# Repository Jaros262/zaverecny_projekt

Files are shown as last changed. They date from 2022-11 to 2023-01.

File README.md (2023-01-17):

# Záverečný projekt
Projekt se bude věnovat hardwaru, konkrétně pak tanku na dálkové ovládání.
# Úvod
Rozhodl jsem vytvořit vozidlo na dálkové ovládání, protože mě práce s Arduino moduly vždy zajímala a vždy jsem chtěl vytvářet modely historických vozidel, primárně pak tanků. 

Hlavním cílem mého projektu bylo vytvoření funkčního tanku, který bude modelově odpovídat předloze historického tanku Tiger I. Tank je vytvořený za pomocí programu Inventor přeložený do formátu gcode a vytištěný na 3D tiskárně. Program tanku je v jazyce Arduino, který je kombinací jazyků C a C++.  

Uživatel se připojí k tanku pomocí ovladače a může si vybrat mezi dvěma módy ovládání, poté již bezstarostně ovládá pohyb tanku a otáčení věže.

> Pro prohlížení souborů doporučuju používat [AUTODESK Viewer](https://360.autodesk.com/viewer "AUTODESK Viewer")

## Rozdělení projektu na branche

1. Základní funkce
   - [x] Kód na pohyb motorů pomocí drátem zapojeným joystickem
   - [x] Schéma zapojení komponentů
   - [x] Video obsahující ukázku funkčnosti
   - [x] Reference
   
2. Prototyp 3D modelu "auta"
   - [x] Samotné části prototypu
   - [x] Screenshoty prototypu
   - [x] Využité technologie

## Cíle

1. Nákup komponentů a diskuze s učiteli
   - [x] Nákup komponentů
   - [X] Diskuze

2. Navrhnout a sestrojit prototip základny
   - [x] Prototyp V1

3. Zprovoznění zařízení BLUETOOTH
   - [x] Vlastnit komponent
   - [x] Zprovoznit komunikaci s mobilem
   - [x] Přehodnocení a konečné rozhodnutí zhotovit vlastní kontroler místo mobilu
   - [x] Návrh kontroleru
   - [ ] Komunikace mezi dvěmi arduino
   - [x] Konstrukce kontroleru
   - [ ] Celkové ovládání modelu skrz kontroler
   
4. Navrhnout kód na pohyb koly
   - [x] Základní Kód
   - [x] Funkce kol
   - [x] Využití joysticku na ovládání kol

5. Navrhnout konečný model tanku
   - [x] Pásy
   - [x] Ozubené kola
   - [x] Systém odpružení pro ostatní kola
   - [x] Dolní část modelu
   - [x] Horní část modelu
   - [x] Věž
   - [X] Dělo
   - [x] Prostory pro moduly v modelu
   - [ ] Detaily modelu
6. Navrhnout finální kód pro controller
   - [X] Funkčnost Joysticků
   - [X] Funkčnost tlačítka/tlačítek (dle potřeby)
   - [X] Funkce dvou rozdílných módů ovládání
   - [X] Funkce Bluetooth
   - [ ] úspěšný test
   - [ ] funkční
7. Navrhnout finální kód pro model
   - [ ] Funkčnost ovládání motorů skrze bluetooth
   - [ ] Funkčnost ovládání serva skrze bluetooth
   - [x] Fungující odpojování baterie
   - [x] Funkce vypnutí celého modelu
   - [ ] úspěšný test
   - [ ] funkční
   
## rozvržení času
- Osobně bych řekl, že jsem na projektu strávil něco mezi 130 - 200 hodin.

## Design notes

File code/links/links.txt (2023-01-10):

DC motors:
https://create.arduino.cc/projecthub/ryanchan/how-to-use-the-l298n-motor-driver-b124c5
switch:
https://arduinogetstarted.com/tutorials/arduino-switch
stm32-connection:
https://www.youtube.com/watch?v=K-jYSysmw9w
OLED Display:
https://www.youtube.com/watch?v=tXaeRzaBwBY
HC-05:
https://www.youtube.com/embed/I2qFXSe0W3w?feature=oembed&autoplay=1
https://create.arduino.cc/projecthub/embeddedlab786/how-to-configure-and-pair-two-hc-05-bluetooth-modules-fa8ce2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
https://howtomechatronics.com/tutorials/arduino/how-to-configure-pair-two-hc-05-bluetooth-module-master-slave-commands/
https://www.instructables.com/Arduino-Two-Way-Communication-Via-Bluetooth-HC-05/
Servo with joystick:
https://maker.pro/arduino/tutorial/how-to-control-servo-motors-with-an-arduino-and-joystick
Button ideas:
https://github.com/poelstra/arduino-multi-button
https://stackoverflow.com/questions/28653134/arduino-button-ispressed-is-not-working
ideas:
https://maker.pro/arduino/projects/how-to-control-an-arduino-robot-with-a-ps4-bluetooth-controller
https://projecthub.arduino.cc/samanfern/c71cd04b-79fd-4d0a-8a4b-b1dacc2f7725
https://www.instructables.com/DIY-Joystick-Controlled-Remote-Car-Using-Arduino/

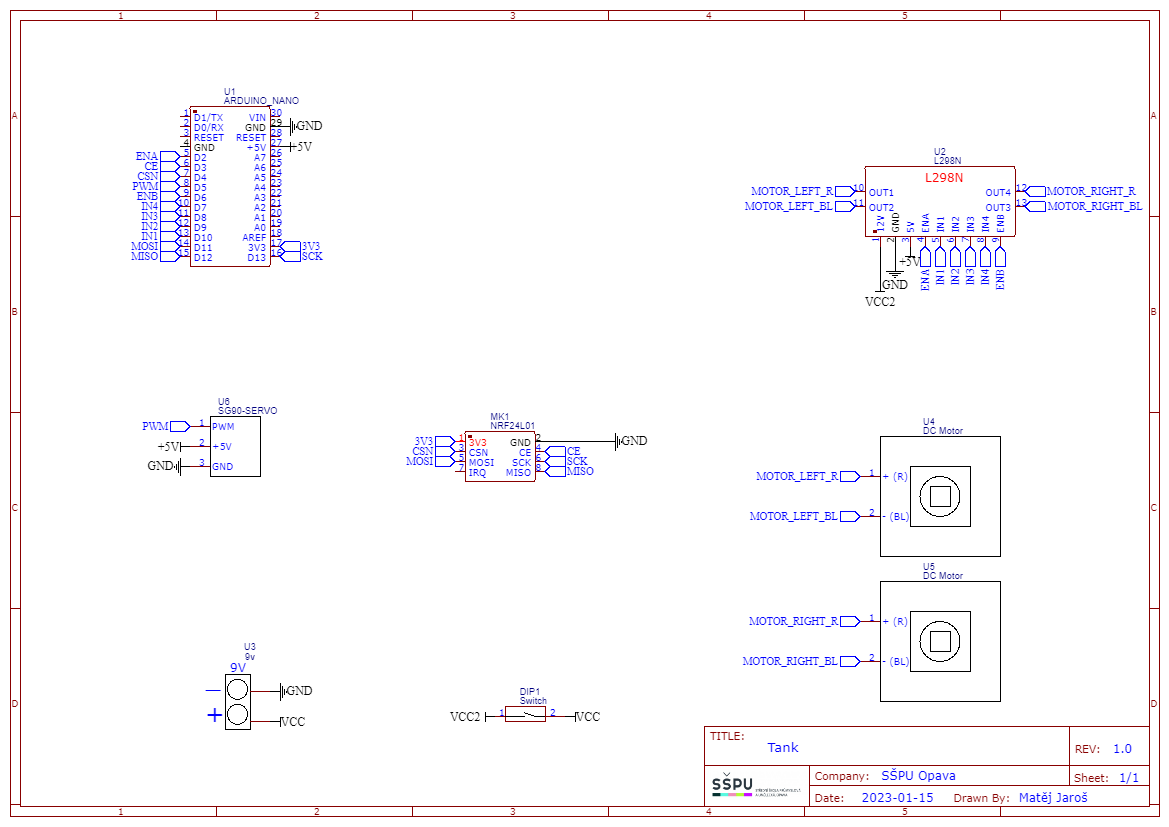
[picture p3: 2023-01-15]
img_files/Schematic_tank_2023-01-15.png

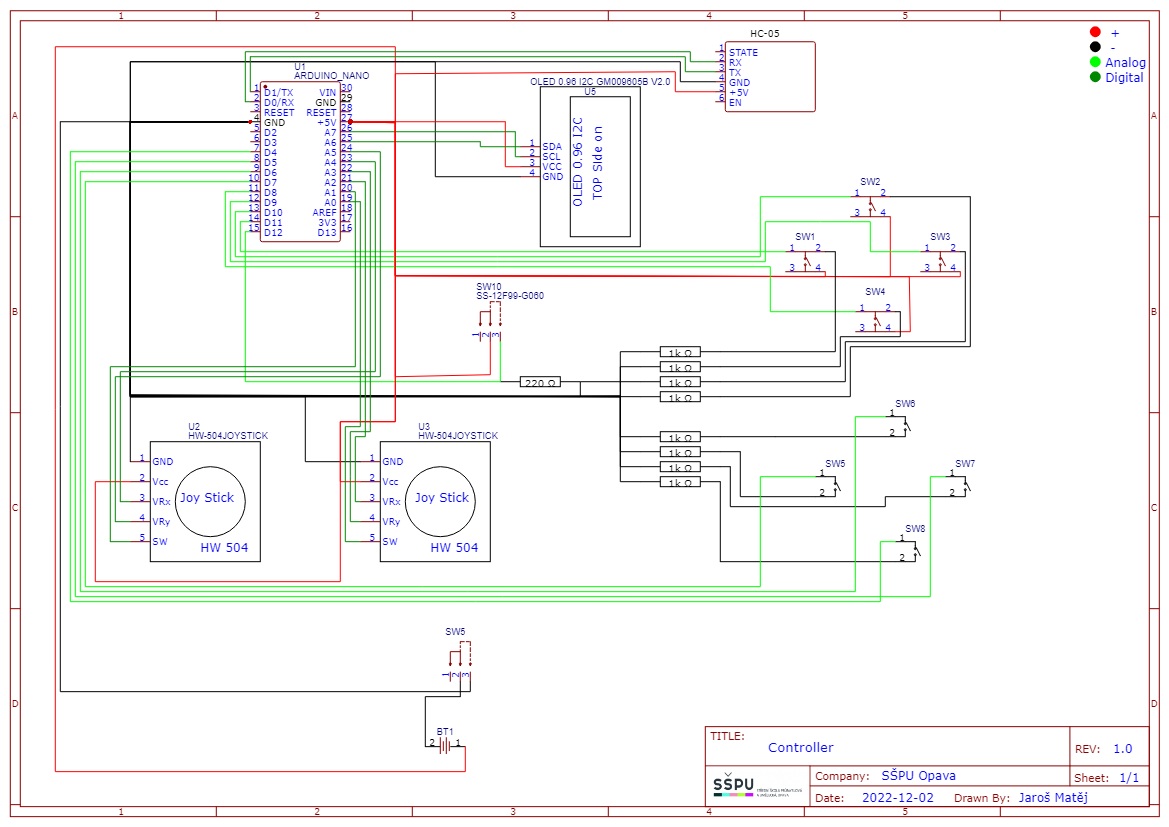
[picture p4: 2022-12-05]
remote-controller/scheme/Schematic_joystick_2022-12-05.png

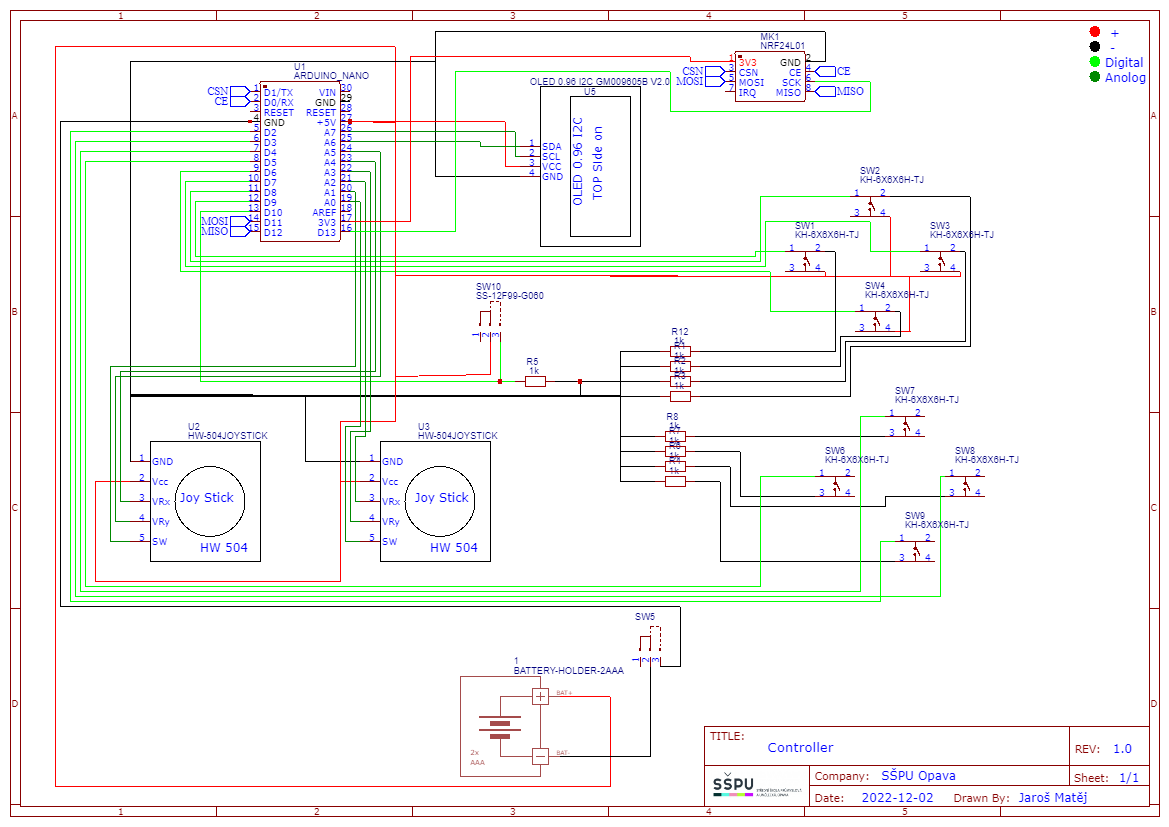
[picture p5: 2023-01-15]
img_files/Schematic_joystick_2023-01-15.png

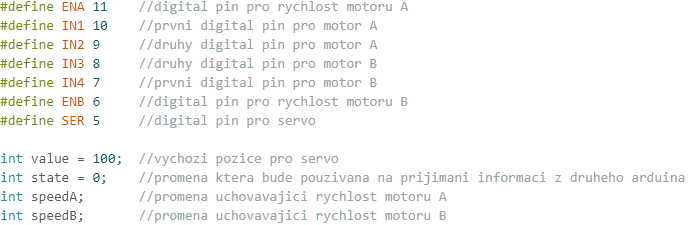
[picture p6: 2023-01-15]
code/img/promenne.png

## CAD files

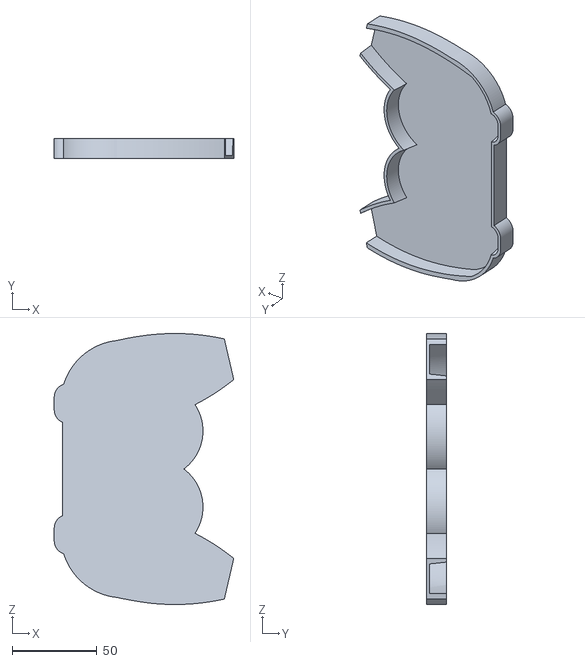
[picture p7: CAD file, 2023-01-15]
remote-controller/stl/ovladac - dolni-nove.stl
106.2 x 12.0 x 160.3

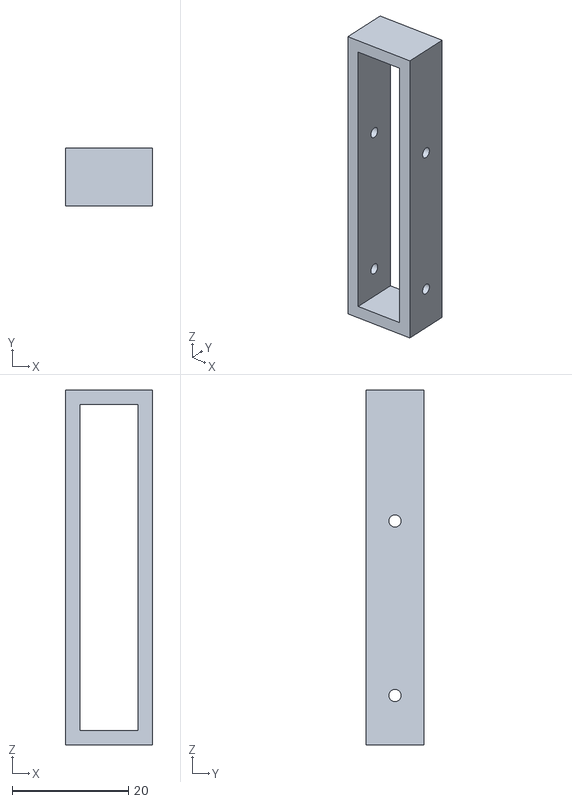
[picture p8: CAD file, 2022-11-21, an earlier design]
model/mechanismus_odpruzeni/stl_files/top.stl
15.0 x 10.0 x 61.0

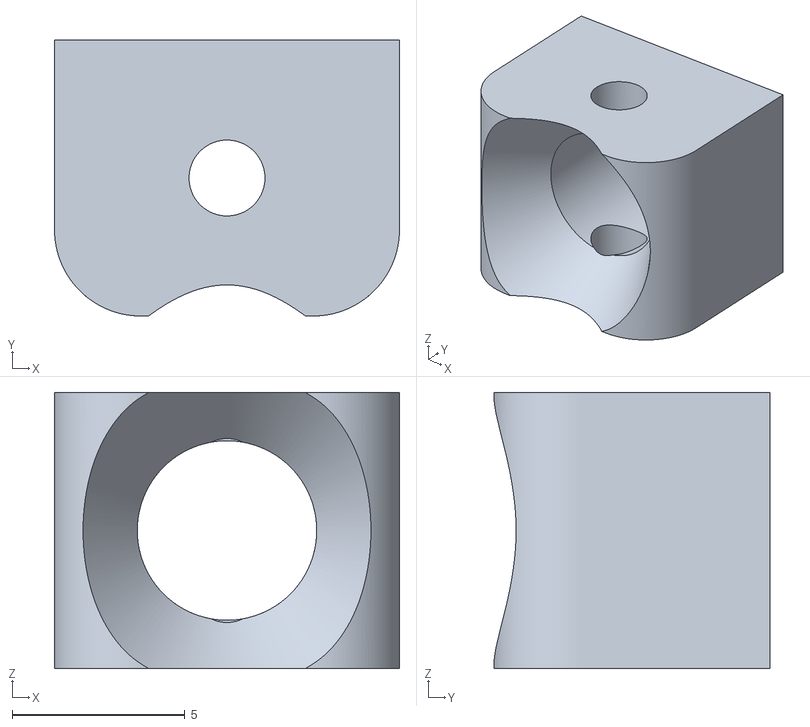
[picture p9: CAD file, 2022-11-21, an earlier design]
model/mechanismus_odpruzeni/stl_files/pist-dolni.stl
10.0 x 8.00 x 8.00

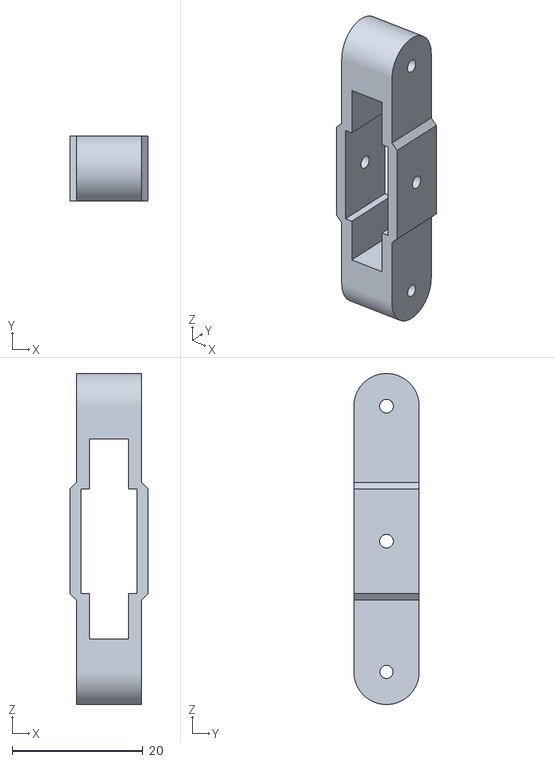
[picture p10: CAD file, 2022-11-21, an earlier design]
model/mechanismus_odpruzeni/stl_files/mid.stl
12.0 x 10.0 x 50.7

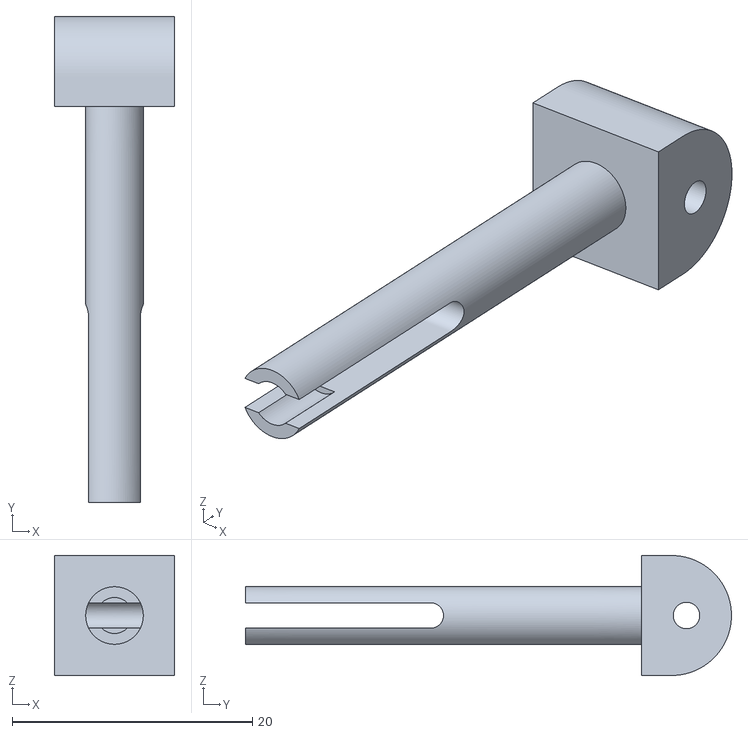
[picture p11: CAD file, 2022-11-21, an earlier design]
model/mechanismus_odpruzeni/stl_files/pist.stl
10.0 x 40.5 x 10.0

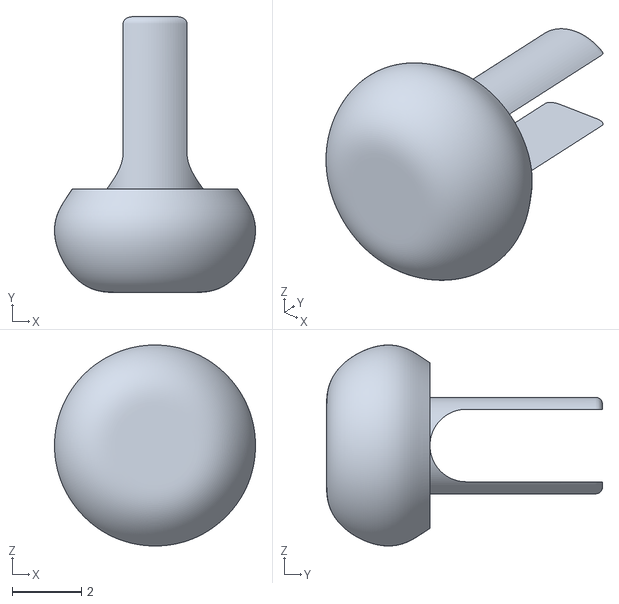
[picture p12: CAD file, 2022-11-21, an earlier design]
model/mechanismus_odpruzeni/stl_files/pist-zatka.stl
5.82 x 8.00 x 5.82

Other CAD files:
autocad/náčrt.dwg
hardware_modules/L298N.ipt
hardware_modules/baterka.ipt
hardware_modules/motor.ipt
hardware_modules/podložka na arduino.ipt
model/delo.ipt
model/dolni-cast.ipt
model/horni-cast (1).ipt
model/horni-cast.ipt
model/inside.ipt
model/mechanismus_odpruzeni/OldVersions/mid.0011.ipt
model/mechanismus_odpruzeni/OldVersions/pist-dolni.0003.ipt
model/mechanismus_odpruzeni/OldVersions/pist-zatka.0003.ipt
model/mechanismus_odpruzeni/OldVersions/pist.0006.iam
model/mechanismus_odpruzeni/OldVersions/pist.0006.ipt
model/mechanismus_odpruzeni/OldVersions/top.0003.ipt
model/mechanismus_odpruzeni/mid.ipt
model/mechanismus_odpruzeni/pist-dolni.ipt
model/mechanismus_odpruzeni/pist-zatka.ipt
model/mechanismus_odpruzeni/pist.iam
model/mechanismus_odpruzeni/pist.ipt
model/mechanismus_odpruzeni/spring.ipt
model/mechanismus_odpruzeni/sroub.ipt
model/mechanismus_odpruzeni/top.ipt
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

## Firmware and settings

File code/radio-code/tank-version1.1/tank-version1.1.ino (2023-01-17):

//SLAVE-REMOTE CAR (TANK)

//KNIHOVNY
#include <Servo.h>            //Libary for servo controll
//#include <SoftwareSerial.h>   //knihovna pro bluetooth
#include <SPI.h>              //radio
#include <nRF24L01.h>         //radio
#include <RF24.h>             //radio

//pins setup
#define ENA 2    //digital pin pro rychlost motoru A
#define IN1 10    //prvni digital pin pro motor A
#define IN2 9     //druhy digital pin pro motor A
#define IN3 8     //druhy digital pin pro motor B
#define IN4 7     //prvni digital pin pro motor B
#define ENB 6     //digital pin pro rychlost motoru B
#define SER 5     //digital pin pro servo
#define CSN_GPIO 4//digital pin for radio
#define CE_GPIO  3//digital pin for radio
//MOSI 11
//MISO 12
//SCK 13
//3V3 3V3

int value = 100;  //vychozi pozice pro servo
//int state = 0;    //promena ktera bude pouzivana na prijimani informaci z druheho arduina
int speedA;       //promena uchovavajici rychlost motoru A
int speedB;       //promena uchovavajici rychlost motoru B

Servo myservo;                      // create servo object to control a servo
                                    // a maximum of eight servo objects can be created
//SoftwareSerial mySerial(3, 4);      // RX, TX - nastaveni pinu modulu hc-05 (bluetooth)

// Hardware configuration
RF24 radio(CE_GPIO, CSN_GPIO);                           // Set up nRF24L01 radio on SPI bus plus pins 7 & 8

const byte Address[6] = "00001";
unsigned char Received_Command = '0';

//Funkce pro ovladani motoru A a B
void vpredMotorA(){
  digitalWrite(IN1, HIGH);
  digitalWrite(IN2, LOW);
}

void vzadMotorA(){
  digitalWrite(IN1, LOW);
  digitalWrite(IN2, HIGH);
}

void statMotorA(){
  digitalWrite(IN1, LOW);
  digitalWrite(IN2, LOW);
}

void vpredMotorB(){
  digitalWrite(IN4, HIGH);
  digitalWrite(IN3, LOW);
}

void vzadMotorB(){
  digitalWrite(IN4, LOW);
  digitalWrite(IN3, HIGH);
}

void statMotorB(){
  digitalWrite(IN4, LOW);
  digitalWrite(IN3, LOW);
}
//--------------------------------

//Funkce pro ovladani serva doleva a doprava
void servoLeft(){
  myservo.write(value);   //udavani pozici servu
  value = value-5;        //ubirani pozice serva
}

void servoRight(){
  myservo.write(value);   //udavani pozici servu
  value = value+5;        //pridavani pozice serva
}
//------------------------------------------

void setup() {                      // put your setup code here, to run once:
  Serial.begin(9600);
  for (byte i=5; i<=11;i++) {       //seting up all digital pins to output
    pinMode(i,OUTPUT);
  }
  //radio setup--------------------------
  radio.begin();
  radio.openReadingPipe(0, Address);
  radio.setPALevel(RF24_PA_MIN);
  radio.startListening();
  Serial.println("START");
  //-------------------------------------
  myservo.attach(5);                //Nastaveni pinu serva na knihovnu <Servo.h>
}

void loop() {
  if (radio.available())    // If the NRF240L01 module received data
  {  
    delay(10);
    radio.read(&Received_Command, 1);
    Serial.print(Received_Command);
  }
  //SPEED SETUP
  analogWrite(ENA,speedA);          //speed of motor A
  analogWrite(ENB,speedB);          //speed of motor B
  //MODE 1 SW==HIGH
    //Ovladani serva---------------------------------------
    if(Received_Command == 8){
      servoLeft();            //vyvolani funkce pohybu serva doleva

    }
    if(Received_Command == 9){
      servoRight();           //vyvolani funkce pohybu serva doprava
    }
    //-----------------------------------------------------

    //Ovladani motoru--------------------------------------
    if(Received_Command == 0){
      while(speedA<=245&&speedB<=245){    //funkce pridavajici rychlost dokud nedojde do maximalni hodnoty
        speedA = speedA + 10;             //adding speed to motor
        speedB = speedB + 10;             //adding speed to motor
      }
      vpredMotorA();                       //vyvolani funkcí k pohybu motoru
      vpredMotorB();
      
    } else if (Received_Command == 1){
        while(speedA<=245&&speedB<=245){  //funkce pridavajici rychlost dokud nedojde do maximalni hodnoty
          speedA = speedA + 10;           //adding speed to motor
          speedB = speedB + 10;           //adding speed to motor
        }
        vzadMotorA();                      //vyvolani funkcí k pohybu motoru
        vzadMotorB();
        
    }else if (Received_Command == 2){
        while(speedA<=245&&speedB<=245){  //funkce pridavajici rychlost dokud nedojde do maximalni hodnoty
          speedA = speedA + 10;           //adding speed to motor
          speedB = speedB + 10;           //adding speed to motor
        }
        vzadMotorA();                      //vyvolani funkcí k pohybu motoru
        vpredMotorB();
        
    }else if (Received_Command == 3){
        while(speedA<=245&&speedB<=245){  //funkce pridavajici rychlost dokud nedojde do maximalni hodnoty
          speedA = speedA + 10;           //adding speed to motor
          speedB = speedB + 10;           //adding speed to motor
        }
        vpredMotorA();                     //vyvolani funkcí k pohybu motoru
        vzadMotorB();
        
    }else {
      while(speedA>=20&&speedB>=20){      //funkce ubírající rychlost dokud nedojde do minimální hodnoty
        speedA = speedA - 20;             //reducing speed of motor
        speedB = speedB - 20;             //reducing speed of motor
      }
        
        statMotorA();                      //vyvolani funkcí k pohybu motoru
        statMotorB();
        
    }
    //-----------------------------------------------------
  //_____________________________________________________

  //MODE 2 SW==LOW  
    //Ovladani motoru--------------------------------------
    if(Received_Command == 4){
      while(speedA<=245){       //funkce pridavajici rychlost dokud nedojde do maximalni hodnoty
        speedA = speedA + 10;   //adding speed to motor
      }
      vpredMotorA();
    } else if (Received_Command == 5){
        while(speedA<=245){     //funkce pridavajici rychlost dokud nedojde do maximalni hodnoty
          speedA = speedA + 10; //adding speed to motor
        }
        vzadMotorA();
    }
    else {
        while(speedA>=20){      //funkce pridavajici rychlost dokud nedojde do maximalni hodnoty
          speedA = speedA - 20; //adding speed to motor
        }
        statMotorA();            //vyvolani funkce k pohybu motoru
    }
    if(Received_Command == 6){
      while(speedB<=245){       //funkce pridavajici rychlost dokud nedojde do maximalni hodnoty
        speedB = speedB + 10;   //adding speed to motor
      }
      vpredMotorB();             //vyvolani funkce k pohybu motoru
    } else if (Received_Command == 7){
        while(speedB<=245){     //funkce pridavajici rychlost dokud nedojde do maximalni hodnoty
          speedB = speedB + 10; //adding speed to motor
        }
        vzadMotorB();           //vyvolani funkce k pohybu motoru
    }
    else {
        while(speedB>=20){      //funkce ubírající rychlost dokud nedojde do minimální hodnoty
          speedB = speedB - 20; //reducing speed of motor
        }
        statMotorB();            //vyvolani funkce k pohybu motoru
    }
    //-----------------------------------------------------
  //_____________________________________________________
}

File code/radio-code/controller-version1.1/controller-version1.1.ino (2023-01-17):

//MASTER-JOYSTICK

//KNIHOVNY
#include <ezButton.h>             //knihovna pro ovladani prepinacu
#include <SPI.h>
#include <nRF24L01.h>
#include <RF24.h>


//second fourth of buttons
#define B8 2
#define B7 3
#define B6 4
#define B5 5
//first fourth of buttons
#define B4 6
#define B3 7
#define B2 8
#define B1 9
//radio
#define CSN_GPIO    1
#define CE_GPIO     2
//switch that will controll switching modes of controlling
//#define SW1 12

//ezButton toggleSwitch(10);        //Switch for toggling modes
RF24 radio(CE_GPIO, CSN_GPIO);
//SoftwareSerial mySerial(2, 3);    // RX, TX - nastaveni pinu modulu hc-05 (bluetooth)

const byte Address[6] = "00001";
unsigned char Tx_command = 0;

int x1;           //Joystick X axis 1 inicialization
int y1;           //Joystick Y axis 1 inicialization
int val1;         //Joystick button 1 inicialization
int x2;           //Joystick X axis 2 inicialization
int y2;           //Joystick Y axis 2 inicialization
int val2;         //Joystick button 2 inicialization
int state = 0;    //promena ktera bude pouzivana na prijimani informaci z druheho arduina
int swState;      //promena ktera bude pouzivana na ukladani statusu spinace


void setup() {
  // put your setup code here, to run once:
  Serial.begin(9600);
  for (byte i=4; i<=12;i++) {           //setting all the pins to output
    pinMode(i,OUTPUT);
  }
  
  radio.begin();
  radio.openWritingPipe(Address);
  radio.setPALevel(RF24_PA_MAX);
  radio.stopListening();
  radio.write(&Tx_command, sizeof(Tx_command));
  //toggleSwitch.setDebounceTime(50);     //set debounce time to 50 milliseconds
}

void loop() {
  // put your main code here, to run repeatedly:
  //toggleSwitch.loop(); // MUST call the loop() function first
  //Bluetooth inicializace-------------------------------
  if(Serial.available() > 0){ // Checks whether data is comming from the serial port
    state = Serial.read(); // Reads the data from the serial port
  }
  //-----------------------------------------------------
  //Joystick X axis 1 inicialization
int val1;         //Joystick button 1 inicialization
int x2;           //Joystick X axis 2 inicialization
int y2;           //Joystick Y axis 2 inicialization
int val2;         //Joystick button 2 inicialization
  //Inicializace analog pinů-----------------------------
  x1 = analogRead(A7);      //Joystick X axis 1
  y1 = analogRead(A6);      //Joystick Y axis 1
  //val1 = analogRead(A0);    //Joystick button 1
  x2 = analogRead(A5);      //Joystick X axis 2
  y2 = analogRead(A4);      //Joystick Y axis 2
  //val2 = analogRead(A3);    //Joystick button 2
  //-----------------------------------------------------
  //Inicializace switche---------------------------------
  //swState = toggleSwitch.getState();
  //-----------------------------------------------------
  //MODE 1 SW HIGH-----------------------------------------
  //while(swState==HIGH){     //prvni poloha spinace, urcujici aktualni mod ovladani
    //Ovladani motoru--------------------------------------
    if(y1<=100){
      Tx_command = 0;      //zasila do tanku pokyn k pohybu
    } else if (y1>=900){
        Tx_command = 1;     //zasila do tanku pokyn k pohybu
    }else if (x1<=100){
        Tx_command = 2;    //zasila do tanku pokyn k pohybu
    }else if (x1>=900){
        Tx_command = 3;   //zasila do tanku pokyn k pohybu
    }
    //-----------------------------------------------------
    //Ovladani serva---------------------------------------
    if(x2<100){
      Tx_command = 8;       //zasila do tanku pokyn k pohybu serva doleva
    }
    if(x2>900){
      Tx_command = 9;      //zasila do tanku pokyn k pohybu serva doprava
    }
    //-----------------------------------------------------
    radio.write(&Tx_command, 1);
    delay(150);
  //}
  //-------------------------------------------------------
  //while(swState==LOW){      //druha poloha spinace, urcujici aktualni mod ovladani
    //Ovladani motoru--------------------------------------
    /*if(y1<=100){
      Tx_command = 4;     //zasila do tanku pokyn k pohybu
    }
    if(y2<=100){
      Tx_command = 5;     //zasila do tanku pokyn k pohybu
    }
    if(y1>=900){
      Tx_command = 6;     //zasila do tanku pokyn k pohybu
    }
    if(y2>=900){
      Tx_command = 7;     //zasila do tanku pokyn k pohybu
    }
    //-----------------------------------------------------
    //Ovladani serva---------------------------------------
    if(B1 == HIGH){
      Tx_command = 8;      //zasila do tanku pokyn k pohybu serva doleva
    }
    if(B2 == HIGH){
      Tx_command = 9;    //zasila do tanku pokyn k pohybu serva doprava
    }
    //-----------------------------------------------------
    radio.write(&Tx_command, 1);
    delay(150);*/
  //}
  //-------------------------------------------------------
}

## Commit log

2022-11-09 model_uvodni_cast
    První díl z mnoha
    [dolni-cast.ipt]
2022-11-09 AutoCad files
    Nákresy s údaji o dílech.
    [náčrt.dwg]
2022-11-21 odpruzeni
    zakladni mechanismus odpruzeni
    [mid.0011.ipt, mid.ipt, mid.stl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]
2022-11-21 update
    updated version
    [náčrt.dwg]
2022-11-30 update_version
    +3 parts
    [náčrt.dwg]
2022-11-30 tank_update_v1.2
    looks like a tank now
    [dolni-cast.ipt, horni-cast.ipt, slozene.iam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]
2022-11-30 added_sticks
    some lil parts
    [spring.ipt, sroub.ipt, tycinka.ipt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]
2022-11-30 wheels&tracks
    added some other parts to have complete model
    [kolo_mensi.ipt, kolo_vetsi.ipt, ozubene-kolo.ipt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]
2022-11-30 delo_added
    dělo přídáno, avšak né finální verze
    [delo.ipt, slozene.iam]
2022-11-30 hardware_modules
    vytvořil jsem si pomocí inventoru všechny (podstatné a rozměrné) elektronické díly.
    [L298N.ipt, baterka.ipt, motor.ipt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]
2022-12-05 controller_model
    první návrh modelu ovladače
    [ovladac.ipt]
2022-12-15 display+switch
    další komponenty
2022-12-20 Mechanismus_odpruzeni_v2
    Zvažování předělání odpružení z obav, že pružiny budou moc tvrdé.
    [pist.ipt]
2022-12-20 Tank_remake
    upraveni tanku. z důvodu nedostatečné šířky
    [delo.ipt, dolni-cast.ipt, horni-cast (1).ipt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]
2023-01-15 aktualizace ovladače
    [controller.0003.iam, controller.iam, ovladac - dole.0007.ipt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]
2023-01-15 new Wheels
    [kolo_mensi.ipt]
2023-01-15 new Wheals
    [ozubene-kolo.ipt, ozubene-kolo_mini.ipt]
